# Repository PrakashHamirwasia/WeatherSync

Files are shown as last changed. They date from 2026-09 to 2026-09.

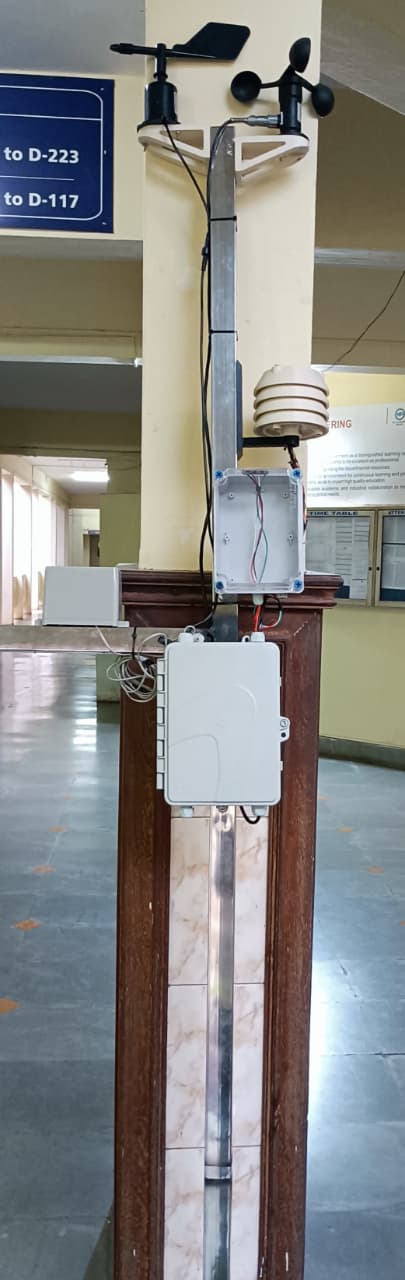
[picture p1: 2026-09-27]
Images/3.jpeg

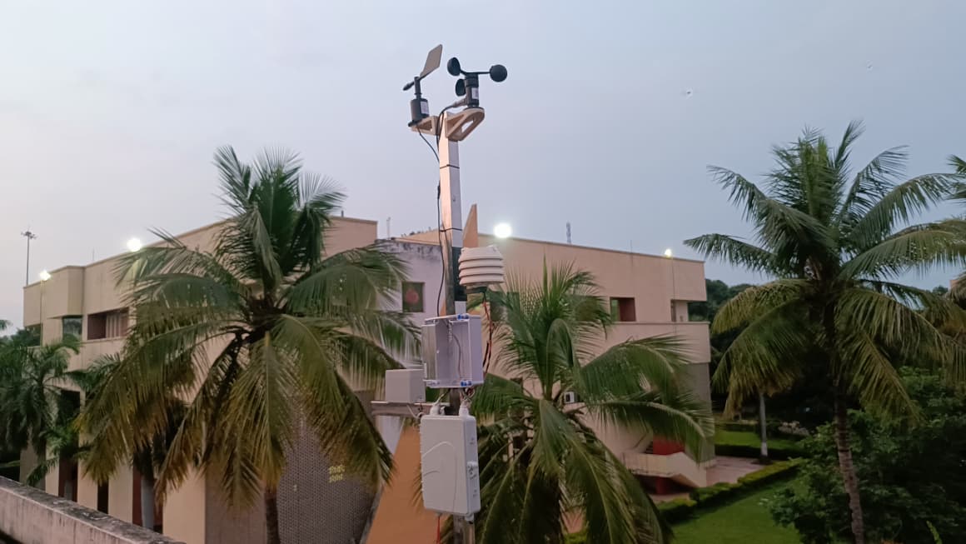
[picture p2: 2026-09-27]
Images/1.jpeg

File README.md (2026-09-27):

# 🌦️ WeatherSync

## Smart IoT-Based Weather Monitoring Station

WeatherSync is an **IoT-enabled weather monitoring system** designed to collect, process, store, and visualize localized environmental data. The system uses an **ESP32-S3** as the primary controller and integrates multiple sensors to measure important meteorological parameters such as temperature, humidity, atmospheric pressure, UV radiation, rainfall, wind speed, and wind direction.

The collected data is transmitted to a cloud-based backend and can be accessed through the **WeatherSync Android application**, enabling remote monitoring and analysis of current and historical weather conditions.

---

## 🎯 Project Objective

The primary objective of WeatherSync is to develop a **cost-effective, scalable, and localized weather monitoring station** capable of continuously collecting environmental data and making it remotely accessible.

The system is intended to provide reliable site-specific weather information for applications such as **agriculture, environmental monitoring, education, research, and smart-campus deployments**.

---

## ✨ Features

- 🌡️ Temperature monitoring
- 💧 Relative humidity monitoring
- 🌡️ Atmospheric pressure measurement
- ☀️ UV radiation monitoring
- 🌧️ Rainfall measurement
- 🌬️ Wind speed measurement
- 🧭 Wind direction measurement
- 📡 IoT-based data communication
- ☁️ Cloud-based data storage
- 📱 Android application for remote monitoring
- 📊 Historical weather-data visualization
- 🛡️ Weather-protected sensor enclosure
- 🌿 3D-printed Gill radiation shield
- 🔄 Periodic weather-data collection
- 👥 Multi-user access to station data

> **Future:** Solar energy integration and LoRa-based communication will be added in future updates.

---

# 🏗️ System Architecture

```text
                    ┌──────────────────────────┐
                    │      Weather Sensors     │
                    │                          │
                    │  • SHT85                 │
                    │  • BMP390                │
                    │  • VEML6070              │
                    │  • Rain Gauge            │
                    │  • Wind Speed Sensor     │
                    │  • Wind Direction Sensor │
                    └────────────┬─────────────┘
                                 │
                                 ▼
                    ┌──────────────────────────┐
                    │        ESP32-S3           │
                    │                          │
                    │  • Sensor Acquisition    │
                    │  • Data Processing       │
                    │  • Communication         │
                    └────────────┬─────────────┘
                                 │
                                 ▼
                    ┌──────────────────────────┐
                    │       MQTT / HiveMQ       │
                    └────────────┬─────────────┘
                                 │
                                 ▼
                    ┌──────────────────────────┐
                    │         Supabase          │
                    │     Cloud Data Storage    │
                    └────────────┬─────────────┘
                                 │
                                 ▼
                    ┌──────────────────────────┐
                    │     WeatherSync App       │
                    │         Flutter           │
                    └──────────────────────────┘

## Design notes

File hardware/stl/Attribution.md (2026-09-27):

# Third-Party 3D Model Attribution

This project includes 3D-printable STL files that are **not original designs**.
This file documents their sources, licenses, and what — if anything — was
modified, as required by the Creative Commons licenses under which they were
shared. Keep this file alongside the STL files wherever they are stored
(`/hardware/stl/` in this repo).

---

## 1. Gill Radiation Shield

| | |
|---|---|
| **File(s)** | `Gill_shield_base.stl` `Gill_shield_middle_plate.stl` `Gill_shield_middle_plate_tab.stl` `Gill_shield_top_plate.stl` |
| **Original title** | *Solar radiation shield* |
| **Creator** | [tkircher](https://www.thingiverse.com/tkircher/designs) |
| **Source** | <https://www.thingiverse.com/thing:2865787> |
| **License** | Creative Commons Attribution-ShareAlike 4.0 International (CC BY-SA 4.0) |
| **License text** | <https://creativecommons.org/licenses/by-sa/4.0/> |
| **Modified?** | **No** — used unmodified, exactly as downloaded. |

> "Solar radiation shield" by tkircher is licensed under CC BY-SA 4.0.

**What this license requires:**
- Attribution to tkircher and a link back to the original design (given above).
- If a *modified* version of this specific file is ever redistributed, it must
  be released under the same CC BY-SA 4.0 license. This does not currently
  apply, since the file here is unmodified — but note it if that ever changes.

---

## 2. Radiation Shield Mounting Holders

| | |
|---|---|
| **File(s)** | `stand_backplate.stl`, `stand_arm.stl` |
| **Original title** | *Gill Shield Weather Station case for RuuviTag* |
| **Creator** | [nerdaxic](https://www.printables.com/social/143845-nerdaxic/models) |
| **Source** | <https://www.printables.com/model/177377-gill-shield-weather-station-case-for-ruuvitag> |
| **License** | Creative Commons Attribution-NonCommercial 4.0 International (CC BY-NC 4.0) |
| **License text** | <https://creativecommons.org/licenses/by-nc/4.0/> |
| **Modified?** | **Partially** — two part files were taken from this design: <br>• `stand_backplate.stl` — used exactly as downloaded, no changes. <br>• `stand_arm.stl` — dimensions were changed to fit this project's mast and enclosure. |

> "Gill Shield Weather Station case for RuuviTag" by nerdaxic is licensed under
> CC BY-NC 4.0.

**What this license requires:**
- Attribution to nerdaxic and a link back to the original design (given above).
- Disclosure that changes were made — noted above for `stand_arm.stl`.
- **Non-commercial use only.** This project is a non-commercial academic/IEEE
  student project, which is within the license's terms. Any commercial use
  would require contacting the original creator directly.
- No ShareAlike clause applies to this license — `stand_arm.stl` is not
  required to carry any particular license if shared, but the attribution and
  disclosure above must still accompany it.

---

## Summary Table

| File | Creator | License | Modified |
|---|---|---|---|
| `Gill_shield_base.stl` `Gill_shield_middle_plate.stl` `Gill_shield_middle_plate_tab.stl` `Gill_shield_top_plate.stl` | tkircher | CC BY-SA 4.0 | No |
| `stand_backplate.stl` | nerdaxic | CC BY-NC 4.0 | No |
| `stand_arm.stl` | nerdaxic | CC BY-NC 4.0 | Yes — dimensions changed |

*Last updated: prepared alongside the WeatherSync Project Report.*

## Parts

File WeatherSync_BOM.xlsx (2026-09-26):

WeatherSync — Bill of Materials
One physical weather station node — electronics, mechanical/weatherproofing materials, assembly hardware and tools. Companion to the WeatherSync Project Report.
Category | Item | Function / Purpose | Interface / Specification | Qty per Station
Electronics & Sensors
Electronics | ESP32-S3 | Main controller and Wi-Fi node | GPIO, I2C, ADC; 3.3V logic | 1
Electronics | SHT85 | Temperature and humidity sensor | I2C (shared bus), SDA->GPIO8, SCL->GPIO9 | 1
Electronics | BMP390 | Barometric pressure sensor | I2C (shared bus) | 1
Electronics | VEML6070 | UV light intensity sensor | I2C (shared bus) | 1
Electronics | DFRobot Tipping Bucket Rain Sensor | Cumulative rainfall measurement | I2C (shared bus), address 0x1D | 1
Electronics | Anemometer (wind speed sensor) | Wind speed measurement | 4-20mA current loop, GPIO7 via 156Ω shunt, ADC1 Ch.6 | 1
Electronics | Wind Direction Sensor SN-3000-FXJT-I20-16 | Wind direction (16-point compass) | 4-20mA current loop, GPIO4 via 150Ω shunt, ADC1 Ch.3 | 1
Electronics | LoRa Module Ra-02 SX1278 | Long-range radio, reserved for a future non-Wi-Fi communication path | Present on circuit; not yet wired into firmware | 1
Mechanical, Enclosure & Weatherproofing
Mechanical | PTFE Breathable Membrane | Lets air/moisture equalise while blocking liquid water | Fitted to sealed electronics + UV enclosures | 2
Mechanical | SS Square Pipe (mounting mast) | Structural mast for mounting sensors and enclosures | Note: drilling SS is difficult — aluminium square pipe recommended for future builds | 1
Mechanical | Gill Radiation Shield (3D Printed) | Shields temp/humidity sensor from direct sun while allowing airflow | Printed on Bambu Lab A1 Mini, PETG filament | 1
Mechanical | Wind Sensor Holders (3D Printed) | Custom mounting holders for shield and wind sensors | 3D printed, PETG filament | 1 set
Mechanical | Waterproof Enclosure (opaque) | Houses ESP32 and wiring, fully sealed | Fitted with PTFE membrane, butyl tape, silicone gel | 1
Mechanical | Transparent Waterproof Enclosure | Houses UV sensor, needs clear sky view | Fitted with PTFE membrane, butyl tape, silicone gel | 1
Mechanical | Waterproof Butyl Tape | Seals enclosure seams and cable entry points | Self-fusing tape | As needed
Mechanical | Silicone Gel | Seals and cushions sensitive joints/connectors against moisture | General purpose sealant | As needed
Electrical Assembly Materials
Assembly | Zero PCB (Perfboard) | Prototyping board for permanent ESP32 + component soldering | Generic perfboard | 1
Assembly | Coated (Insulated) Wire Set | Point-to-point connections: board, sensors, connectors | Assorted gauges | As needed
Assembly | 3-Pin JST Connector | Secure, lockable, field-replaceable sensor connections | 3-pin, locking | As needed
Assembly | 4-Pin JST Connector | Secure, lockable, field-replaceable sensor connections | 4-pin, locking | As needed
Tools Required (Not Consumed Per Station)
Tools | Soldering Iron, Solder Wire, Flux, Cleaning Brush | Permanent electrical connections on the Zero PCB | Standard soldering kit | 1 set (shared)
Tools | Wire Stripper | Prepares insulated wire ends | Standard hand tool | 1 (shared)
Tools | Nose Plier | Precise bending/holding of small wires and connector pins | Standard hand tool | 1 (shared)
Tools | Drill Machine | Mounting holes in mast and enclosures | Standard power tool | 1 (shared)
Tools | Cutter Machine | Cutting wire, tape, and mechanical parts to length | Standard workshop tool | 1 (shared)
Quantities are per single station node. "As needed" items (wire, tape, connectors, sealant, tools) depend on build scale and are not fixed per-unit quantities. Status labels follow the project report's convention: Working/Verified = built and field-tested; Planned = present but not yet active.

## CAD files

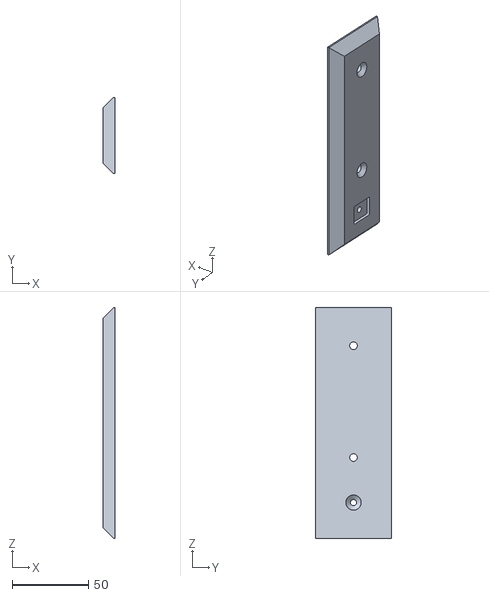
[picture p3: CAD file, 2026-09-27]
hardware/stl/stand_backplate.stl
8.00 x 50.0 x 151.2

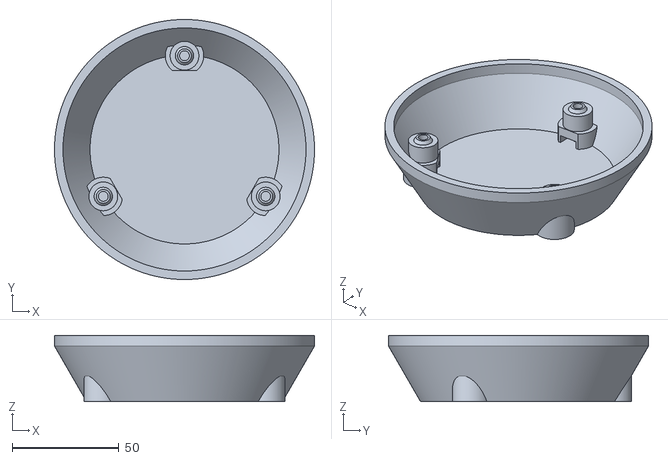
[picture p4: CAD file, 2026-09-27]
hardware/stl/Gill_shield_top_plate.stl
122.0 x 122.0 x 31.0

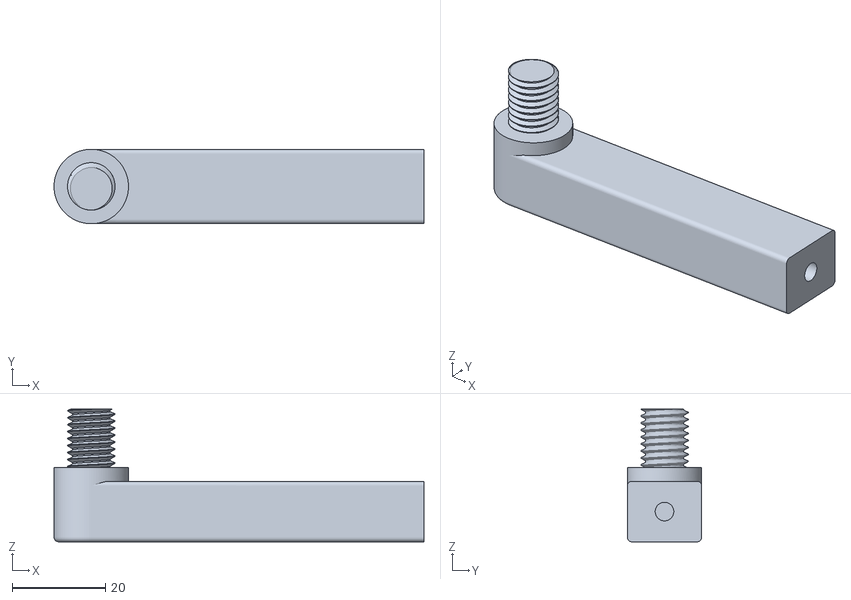
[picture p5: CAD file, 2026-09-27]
hardware/stl/stand_arm.stl
79.5 x 16.0 x 28.5

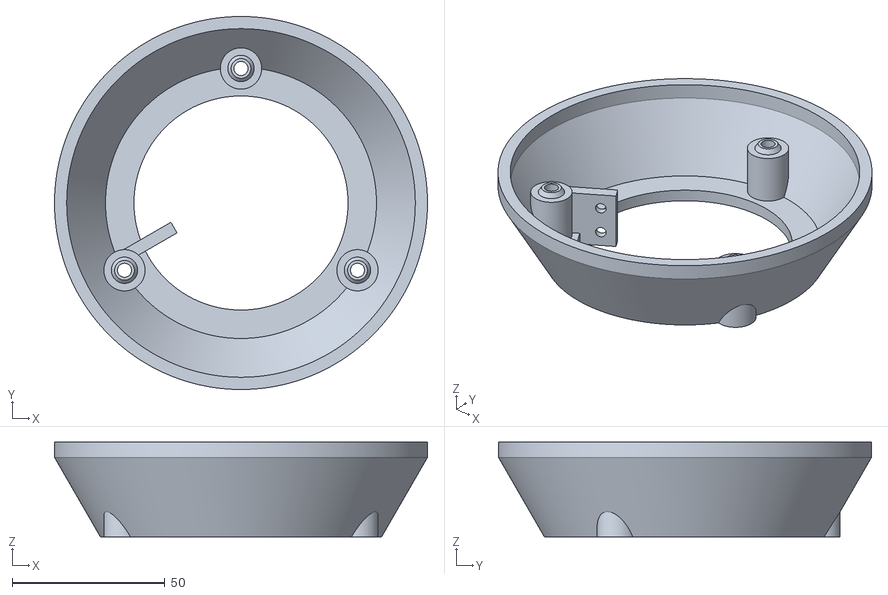
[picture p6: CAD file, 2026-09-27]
hardware/stl/Gill_shield_middle_plate_tab.stl
122.0 x 122.0 x 31.0

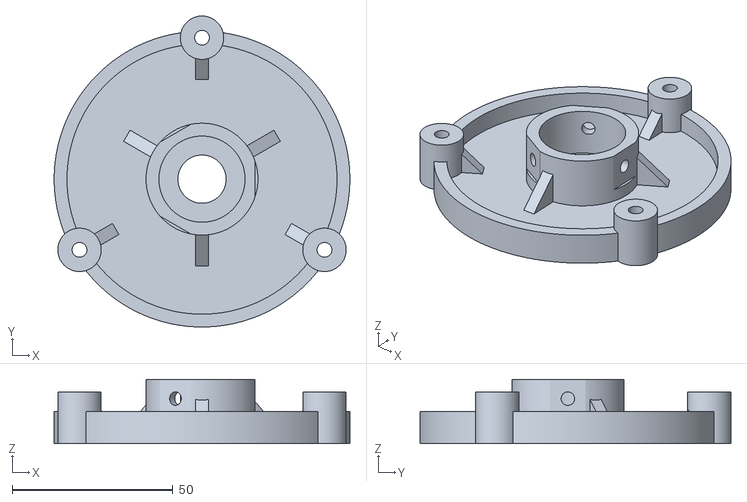
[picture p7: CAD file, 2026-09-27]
hardware/stl/Gill_shield_base.stl
92.0 x 96.8 x 20.0

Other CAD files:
hardware/stl/Gill_shield_middle_plate.stl

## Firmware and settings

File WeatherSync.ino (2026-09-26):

// ════════════════════════════════════════════════════════════════════
//  UNIFIED WEATHER STATION — ESP32-S3
//  TWO-TIER SAMPLING / PUBLISH REVISION
//
//  Sensors:
//    1. Wind Direction Sensor        (4–20 mA current loop, GPIO4)
//    2. VEML6070  UV Sensor          (I2C)
//    3. BMP390    Pressure/Temp/Alt  (I2C)
//    4. DFRobot   Tipping Bucket     (I2C)
//    5. SHT85     Temp/Humidity      (I2C)
//    6. Anemometer 4–20 mA           (Analog, GPIO7)
//
//  SAMPLING / PUBLISH STRATEGY (this revision):
//    • FAST tier  (every FAST_SAMPLE_MS,  default 3s):
//        wind speed, wind direction, rain cumulative poll.
//        Wind is gusty — sampling every 30s+ throws away real peaks,
//        so wind speed/direction are accumulated frequently and
//        reduced to avg + gust at publish time.
//    • SLOW tier  (every SLOW_SAMPLE_MS, default 30s):
//        pressure, temp, humidity, UV. These drift slowly, so
//        frequent sampling isn't needed — accumulated for averaging.
//    • MQTT publish (every MQTT_PUBLISH_MS, default 30s):
//        latest instantaneous readings, for the app's live dashboard.
//        Retained, small payload, no averaging — "what's happening now".
//    • SUPABASE publish (every SUPABASE_PUBLISH_MS, default 5 min):
//        averaged/aggregated values since the last Supabase publish —
//        this is the time-series the app's forecasting/trend logic
//        (pressure trend, dew point, rain-rate windows) runs on.
//        Accumulators reset after each Supabase publish.
//
//  IMPORTANT — SUPABASE RPC SIGNATURE CHANGED:
//    The log_reading RPC now needs to accept the AGGREGATE field set
//    below (pressure_hpa_avg, wind_speed_ms_gust, rain_mm_interval,
//    etc.) instead of the older single-sample field set. Update your
//    Supabase function signature to match p_* params in
//    postAggregateToSupabase() before flashing, or the RPC calls will
//    fail with a parameter-mismatch error.
//
//  REQUIRED LIBRARIES (Arduino Library Manager):
//    • PubSubClient           (Nick O'Leary)
//    • ArduinoJson             (Benoit Blanchon) — v6.x API used below
//    • DFRobot_RainfallSensor  (DFRobot) — I2C class used
//    (WiFi, WiFiClientSecure, HTTPClient ship with the ESP32 core)
// ════════════════════════════════════════════════════════════════════

// ────────────────────────────────────────────────────────────────────
//  WIRING SUMMARY  (ESP32-S3) — unchanged from previous revision
//
//  ── SHARED I2C BUS (SDA=GPIO8, SCL=GPIO9) ──────────────────────
//  Pull-ups: GPIO8 — 10kΩ — 3V3 | GPIO9 — 10kΩ — 3V3
//  VEML6070 (UV)        VDD→3V3  GND→GND  SDA→GPIO8  SCL→GPIO9
//  BMP390 (Pressure)    VCC→3V3  GND→GND  SDA→GPIO8  SCL→GPIO9
//  SHT85 (Temp/RH)      VDD→3V3  GND→GND  SDA→GPIO8  SCL→GPIO9
//  DFRobot Tipping Bkt  VCC→3V3  GND→GND  SDA→GPIO8  SCL→GPIO9  (0x1D)
//
//  ── Anemometer 4–20 mA — WIND SPEED (Analog) ─────────────────────
//    Signal → GPIO7 (ADC1_CH6), 156Ω shunt → GND
//
//  ── Wind Direction Sensor 4–20 mA (Analog) ────────────────────────
//    Signal → GPIO4 (ADC1_CH3), 150Ω shunt → GND
//
//  Enclosures (per your build):
//    • BMP390 + SHT85 → vented PETG radiation shield
//    • VEML6070       → sealed transparent weatherproof box, ePTFE
//                        membrane for pressure/humidity equalization
//    • ESP32 + power  → sealed opaque weatherproof box, ePTFE membrane
//    • Wind sensors   → mast-mounted, IP-rated, no shield needed
// ────────────────────────────────────────────────────────────────────

#include <Wire.h>
#include <Adafruit_BMP3XX.h>
#include "SHT85.h"
#include "DFRobot_RainfallSensor.h"
#include <WiFi.h>
#include <WiFiClientSecure.h>
#include <PubSubClient.h>
#include <HTTPClient.h>
#include <ArduinoJson.h>
#include <math.h>

// ════════════════════════════════════════════════════════════════════
//  NETWORK / BACKEND CONFIG — fill these in before flashing
// ════════════════════════════════════════════════════════════════════
#define WIFI_SSID         "IEEE_ITWEATHERSTATION"
#define WIFI_PASSWORD     "Shourya@0210"
#define STATION_ID        "ws-001"

#define HIVEMQ_HOST       ""
#define HIVEMQ_PORT       
#define HIVEMQ_USERNAME   ""
#define HIVEMQ_PASSWORD   ""

// Supabase — same project as the app's EXPO_PUBLIC_SUPABASE_URL /
// EXPO_PUBLIC_SUPABASE_ANON_KEY values.
#define SUPABASE_URL      ""
#define SUPABASE_ANON_KEY ""

// ════════════════════════════════════════════════════════════════════
//  TIMING — the two-tier schedule
// ════════════════════════════════════════════════════════════════════
#define FAST_SAMPLE_MS       3000UL      // wind + rain poll
#define SLOW_SAMPLE_MS       30000UL     // pressure/temp/humidity/UV poll
#define MQTT_PUBLISH_MS      30000UL     // live snapshot to app
#define SUPABASE_PUBLISH_MS  300000UL    // 5-min averaged aggregate

// ════════════════════════════════════════════════════════════════════
//  PIN DEFINITIONS
// ════════════════════════════════════════════════════════════════════
#define I2C_SDA          8
#define I2C_SCL          9

#define ANEM_PIN          7
#define R_SHUNT         156.0f
#define WS_MAX_MPS       30.0f

#define WIND_DIR_PIN      4
#define WIND_DIR_SHUNT  150.0f

#define VEML6070_ADDR_L  0x38
#define VEML6070_ADDR_H  0x39

#define BMP390_ADDR      0x77
#define SEA_LEVEL_HPA  1008.0f

#define SHT85_ADDRESS    0x44

Adafruit_BMP3XX bmp;
SHT85 sht(SHT85_ADDRESS);
DFRobot_RainfallSensor_I2C rainSensor(&Wire);

// ════════════════════════════════════════════════════════════════════
//  MQTT / Networking globals
// ════════════════════════════════════════════════════════════════════
WiFiClientSecure mqttNet;
PubSubClient     mqttClient(mqttNet);

String topicData;
String topicStatus;
String mqttClientId;

unsigned long lastMqttAttempt = 0;
const unsigned long MQTT_RETRY_MS = 5000;

// ════════════════════════════════════════════════════════════════════
//  Wind Direction — 16-point compass lookup
// ════════════════════════════════════════════════════════════════════
const char* compassDir16[] = {
  "N", "NNE", "NE", "ENE", "E", "ESE", "SE", "SSE",
  "S", "SSW", "SW", "WSW", "W", "WNW", "NW", "NNW"
};

// ════════════════════════════════════════════════════════════════════
//  LATEST INSTANTANEOUS READINGS — used for the MQTT live snapshot
// ════════════════════════════════════════════════════════════════════
float windDir_mA       = 0;
float windDir_deg       = -1;
String windDir_compass  = "ERR";

float anem_mps = 0, anem_kmh = 0, anem_mA = 0;

float lastPressureHpa = 0;
float lastTempC       = 0;
float lastHumidityPct = 0;
uint16_t lastUvRaw     = 0xFFFF;

float latestRainCumulative = 0;   // mm, lifetime total from sensor

// ════════════════════════════════════════════════════════════════════
//  FAST-TIER ACCUMULATORS (wind, rain) — reset every Supabase publish
// ════════════════════════════════════════════════════════════════════
float windSpeedSum   = 0;
int   windSpeedCount = 0;
float windSpeedGust  = 0;         // max instantaneous speed this window

float windDirSumSin = 0;
float windDirSumCos = 0;
int   windDirCount   = 0;         // only valid (non-error) samples counted

float rainAtLastSupabasePublish = -1;  // -1 = not yet initialized

// ════════════════════════════════════════════════════════════════════
//  SLOW-TIER ACCUMULATORS (pressure, temp, humidity, UV)
// ════════════════════════════════════════════════════════════════════
float pressureSum = 0; int pressureCount = 0;
float tempSum     = 0; int tempCount     = 0;
float humiditySum = 0; int humidityCount = 0;
float uvSum       = 0; int uvCount       = 0;

float uvAvgPrevWindow = -1;   // previous 5-min UV avg, for sudden-drop flag

// ════════════════════════════════════════════════════════════════════
//  Scheduling
// ════════════════════════════════════════════════════════════════════
unsigned long lastFastSample     = 0;
unsigned long lastSlowSample     = 0;
unsigned long lastMqttPublish    = 0;
unsigned long lastSupabasePublish = 0;


// ════════════════════════════════════════════════════════════════════
//  Read Wind Direction (4-20mA current loop via 150Ω shunt on GPIO4)
// ════════════════════════════════════════════════════════════════════
void readWindDirection() {
  int   raw  = analogRead(WIND_DIR_PIN);
  float volt = (raw / 4095.0f) * 3.3f;
  float mA   = (volt / WIND_DIR_SHUNT) * 1000.0f;

  if (mA < 3.5f) {
    windDir_mA = mA;
    windDir_compass = "ERR:OpenLoop";
    windDir_deg = -1;
    return;
  }

  mA = constrain(mA, 4.0f, 20.0f);
  windDir_mA = mA;

  float x   = mA - 4.0f;
  int   idx = ((int)roundf(x)) % 16;
  if (idx < 0) idx += 16;

  windDir_deg     = idx * 22.5f;
  windDir_compass = String(compassDir16[idx]);
}

// ════════════════════════════════════════════════════════════════════
//  Read Anemometer (4–20 mA analog) — WIND SPEED
// ════════════════════════════════════════════════════════════════════
void readAnemometer() {
  int   raw  = analogRead(ANEM_PIN);
  float volt = (raw / 4095.0f) * 3.3f;
  anem_mA    = constrain((volt / R_SHUNT) * 1000.0f, 4.0f, 20.0f);
  anem_mps   = (anem_mA - 4.0f) / 16.0f * WS_MAX_MPS;
  anem_kmh   = anem_mps * 3.6f;
}

// ════════════════════════════════════════════════════════════════════
//  Read UV (VEML6070)
// ════════════════════════════════════════════════════════════════════
uint16_t readVEML6070() {
  uint16_t hi = 0, lo = 0;

  Wire.requestFrom((uint8_t)VEML6070_ADDR_H, (uint8_t)1);
  uint32_t t = millis();
  while (!Wire.available()) { if (millis()-t > 100) return 0xFFFF; }
  hi = Wire.read();

  Wire.requestFrom((uint8_t)VEML6070_ADDR_L, (uint8_t)1);
  t = millis();
  while (!Wire.available()) { if (millis()-t > 100) return 0xFFFF; }
  lo = Wire.read();

  return (hi << 8) | lo;
}

// ════════════════════════════════════════════════════════════════════
//  FAST TIER — wind + rain, sampled every FAST_SAMPLE_MS
// ════════════════════════════════════════════════════════════════════
void sampleFast() {
  readAnemometer();
  readWindDirection();

  // Wind speed: accumulate for avg, track gust (max)
  windSpeedSum += anem_mps;
  windSpeedCount++;
  if (anem_mps > windSpeedGust) windSpeedGust = anem_mps;

  // Wind direction: vector average (handles the 360°/0° wraparound
  // correctly, unlike a naive arithmetic mean of degrees)
  if (windDir_deg >= 0) {
    float rad = windDir_deg * (PI / 180.0f);
    windDirSumSin += sinf(rad);
    windDirSumCos += cosf(rad);
    windDirCount++;
  }

  // Rain: just refresh the latest cumulative reading; the interval
  // delta is computed at Supabase-publish time, not here.
  latestRainCumulative = rainSensor.getRainfall();
  if (rainAtLastSupabasePublish < 0) {
    // first-ever sample after boot — seed the baseline so the first
    // interval isn't inflated by the sensor's full lifetime total
    rainAtLastSupabasePublish = latestRainCumulative;
  }
}

// ════════════════════════════════════════════════════════════════════
//  SLOW TIER — pressure/temp/humidity/UV, sampled every SLOW_SAMPLE_MS
// ════════════════════════════════════════════════════════════════════
void sampleSlow() {
  if (bmp.performReading()) {
    lastPressureHpa = bmp.pressure / 100.0f;
    pressureSum += lastPressureHpa;
    pressureCount++;
  }

  sht.read();
  lastTempC = sht.getTemperature();
  lastHumidityPct = sht.getHumidity();
  tempSum += lastTempC;
  tempCount++;
  humiditySum += lastHumidityPct;
  humidityCount++;

  uint16_t uvRaw = readVEML6070();
  if (uvRaw != 0xFFFF) {
    lastUvRaw = uvRaw;
    uvSum += uvRaw;
    uvCount++;
  }
}

// ════════════════════════════════════════════════════════════════════
//  WiFi
// ════════════════════════════════════════════════════════════════════
void connectWiFi() {
  Serial.print("[WiFi] Connecting to ");
  Serial.print(WIFI_SSID);
  WiFi.mode(WIFI_STA);
  WiFi.begin(WIFI_SSID, WIFI_PASSWORD);

  unsigned long start = millis();
  while (WiFi.status() != WL_CONNECTED && millis() - start < 20000) {
    delay(400);
    Serial.print(".");
  }

  if (WiFi.status() == WL_CONNECTED) {
    Serial.print(" connected, IP: ");
    Serial.println(WiFi.localIP());
  } else {
    Serial.println(" FAILED — will keep retrying in loop()");
  }
}

// ════════════════════════════════════════════════════════════════════
//  MQTT — non-blocking connect/reconnect with LWT
// ════════════════════════════════════════════════════════════════════
void mqttReconnect() {
  if (mqttClient.connected()) return;
  if (millis() - lastMqttAttempt < MQTT_RETRY_MS) return;
  lastMqttAttempt = millis();

  if (WiFi.status() != WL_CONNECTED) return;

  Serial.print("[MQTT] Connecting to HiveMQ... ");

  bool ok = mqttClient.connect(
    mqttClientId.c_str(),
    HIVEMQ_USERNAME, HIVEMQ_PASSWORD,
    topicStatus.c_str(), 1, true, "offline"
  );

  if (ok) {
    Serial.println("connected");
    mqttClient.publish(topicStatus.c_str(), "online", true);
  } else {
    Serial.print("failed, rc=");
    Serial.println(mqttClient.state());
  }
}

// ════════════════════════════════════════════════════════════════════
//  MQTT PUBLISH — live snapshot for the app dashboard (every 30s)
//  Uses the LATEST instantaneous readings, not averages — this is
//  meant to feel "live", not smoothed.
// ════════════════════════════════════════════════════════════════════
void publishMqttSnapshot() {
  StaticJsonDocument<384> doc;
  doc["temp_c"]        = lastTempC;
  doc["humidity_pct"]  = lastHumidityPct;
  doc["pressure_hpa"]  = lastPressureHpa;
  doc["rain_mm"]       = latestRainCumulative;
  doc["wind_speed_ms"] = anem_mps;
  if (windDir_deg >= 0) doc["wind_dir_deg"] = windDir_deg;
  if (lastUvRaw != 0xFFFF) doc["uv_index"] = lastUvRaw;
  doc["ts"] = (uint32_t)(millis() / 1000);

  char payload[400];
  size_t n = serializeJson(doc, payload, sizeof(payload));

  if (mqttClient.connected()) {
    bool ok = mqttClient.publish(topicData.c_str(), (const uint8_t*)payload, n, true);
    Serial.print("[MQTT] live snapshot: ");
    Serial.println(ok ? "ok" : "FAILED");
  } else {
    Serial.println("[MQTT] skipped — not connected");
  }
}

// ════════════════════════════════════════════════════════════════════
//  SUPABASE PUBLISH — averaged aggregate for the trailing 5-min
//  window. This is the data the app's forecasting/trend logic reads.
// ════════════════════════════════════════════════════════════════════
void postAggregateToSupabase(float pressureAvg, float tempAvg, float humidityAvg,
                              float uvAvg, bool uvSuddenDrop,
                              float windSpeedAvg, float windSpeedGustVal,
                              float windDirAvg,
                              float rainIntervalMm, float rainCumulativeMm) {
  if (WiFi.status() != WL_CONNECTED) return;

  WiFiClientSecure client;
  client.setInsecure();  // dev/test only — pin the CA for production

  HTTPClient http;
  String url = String(SUPABASE_URL) + "/rest/v1/rpc/log_reading";
  http.begin(client, url);
  http.addHeader("Content-Type", "application/json");
  http.addHeader("apikey", SUPABASE_ANON_KEY);
  http.addHeader("Authorization", String("Bearer ") + SUPABASE_ANON_KEY);

  // NOTE: these param names must match your Supabase RPC signature.
  // The RPC needs updating from the old single-sample field set to
  // this aggregate field set before this will succeed.
  StaticJsonDocument<512> body;
  body["p_station_id"]          = STATION_ID;
  body["p_pressure_hpa_avg"]    = pressureAvg;
  body["p_temp_c_avg"]          = tempAvg;
  body["p_humidity_pct_avg"]    = humidityAvg;
  if (uvAvg >= 0) body["p_uv_raw_avg"] = uvAvg;
  body["p_uv_sudden_drop"]      = uvSuddenDrop;
  body["p_wind_speed_ms_avg"]   = windSpeedAvg;
  body["p_wind_speed_ms_gust"]  = windSpeedGustVal;
  if (windDirAvg >= 0) body["p_wind_dir_deg_avg"] = windDirAvg;
  body["p_rain_mm_interval"]    = rainIntervalMm;
  body["p_rain_mm_cumulative"]  = rainCumulativeMm;

  String payload;
  serializeJson(body, payload);

  int code = http.POST(payload);
  if (code > 0 && code < 300) {
    Serial.print("[Supabase] aggregate log OK, code ");
    Serial.println(code);
  } else {
    Serial.print("[Supabase] aggregate log FAILED, code ");
    Serial.println(code);
  }
  http.end();
}

// ════════════════════════════════════════════════════════════════════
//  Reduce the 5-min accumulators to an aggregate and publish, then
//  reset for the next window.
// ════════════════════════════════════════════════════════════════════
void publishAndResetAggregates() {
  float pressureAvg = (pressureCount > 0) ? (pressureSum / pressureCount) : lastPressureHpa;
  float tempAvg      = (tempCount > 0)     ? (tempSum / tempCount)         : lastTempC;
  float humidityAvg  = (humidityCount > 0) ? (humiditySum / humidityCount) : lastHumidityPct;
  float uvAvg         = (uvCount > 0) ? (uvSum / uvCount) : -1;

  bool uvSuddenDrop = false;
  if (uvAvg >= 0 && uvAvgPrevWindow >= 0) {
    // Flag if this window's average UV dropped more than 40% from
    // the previous window — a possible fast-moving-cloud/rain signal.
    uvSuddenDrop = (uvAvg < uvAvgPrevWindow * 0.6f);
  }
  if (uvAvg >= 0) uvAvgPrevWindow = uvAvg;

  float windSpeedAvg = (windSpeedCount > 0) ? (windSpeedSum / windSpeedCount) : 0;

  float windDirAvg = -1;
  if (windDirCount > 0) {
    float rad = atan2f(windDirSumSin, windDirSumCos);
    float deg = rad * (180.0f / PI);
    if (deg < 0) deg += 360.0f;
    windDirAvg = deg;
  }

  float rainInterval = 0;
  if (rainAtLastSupabasePublish >= 0) {
    rainInterval = latestRainCumulative - rainAtLastSupabasePublish;
    if (rainInterval < 0) rainInterval = 0;  // guard against a sensor reset
  }

  Serial.println("[Aggregate] Publishing 5-min window to Supabase:");
  Serial.print("  Pressure avg: "); Serial.print(pressureAvg, 2); Serial.println(" hPa");
  Serial.print("  Temp avg: ");     Serial.print(tempAvg, 2);     Serial.println(" C");
  Serial.print("  Humidity avg: "); Serial.print(humidityAvg, 2); Serial.println(" %RH");
  Serial.print("  UV avg: ");       Serial.print(uvAvg, 1);
  Serial.print("   Sudden drop: "); Serial.println(uvSuddenDrop ? "YES" : "no");
  Serial.print("  Wind avg: ");     Serial.print(windSpeedAvg, 2);
  Serial.print(" m/s   Gust: ");    Serial.print(windSpeedGust, 2); Serial.println(" m/s");
  Serial.print("  Wind dir avg: "); Serial.print(windDirAvg, 1); Serial.println(" deg");
  Serial.print("  Rain interval: ");Serial.print(rainInterval, 2);
  Serial.print(" mm   Cumulative: ");Serial.print(latestRainCumulative, 2); Serial.println(" mm");

  postAggregateToSupabase(pressureAvg, tempAvg, humidityAvg,
                           uvAvg, uvSuddenDrop,
                           windSpeedAvg, windSpeedGust,
                           windDirAvg,
                           rainInterval, latestRainCumulative);

  // Reset accumulators for the next 5-min window
  windSpeedSum = 0; windSpeedCount = 0; windSpeedGust = 0;
  windDirSumSin = 0; windDirSumCos = 0; windDirCount = 0;
  pressureSum = 0; pressureCount = 0;
  tempSum = 0; tempCount = 0;
  humiditySum = 0; humidityCount = 0;
  uvSum = 0; uvCount = 0;
  rainAtLastSupabasePublish = latestRainCumulative;
}
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
void loop() {
  if (WiFi.status() != WL_CONNECTED) {
    connectWiFi();
  }
  mqttReconnect();
  mqttClient.loop();

  unsigned long now = millis();

  // FAST TIER — wind + rain
  if (now - lastFastSample >= FAST_SAMPLE_MS) {
    lastFastSample = now;
    sampleFast();
  }

  // SLOW TIER — pressure/temp/humidity/UV
  if (now - lastSlowSample >= SLOW_SAMPLE_MS) {
    lastSlowSample = now;
    sampleSlow();
  }

  // MQTT — live snapshot for the app
  if (now - lastMqttPublish >= MQTT_PUBLISH_MS) {
    lastMqttPublish = now;
    publishMqttSnapshot();
  }

  // SUPABASE — 5-min averaged aggregate for forecasting/trend data
  if (now - lastSupabasePublish >= SUPABASE_PUBLISH_MS) {
    lastSupabasePublish = now;
    publishAndResetAggregates();
  }
}
